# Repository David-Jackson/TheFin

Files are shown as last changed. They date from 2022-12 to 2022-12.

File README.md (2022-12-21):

# The Fin
## v1.03

The Fin is a straight Talon mag fed pump action springer in a small compact frame. Coming in at around 15in (390mm) long! The blaster packs an Espyr spring volume with a side mounted mag to help keep the blaster compact (this is also how I came up with the name for it). Two threaded rods make up the trigger mechanism and the reload action. The rods are hidden behind the center shroud for aesthetics. The blaster utilizes a turn-around much like the Lynx or SLAB to transfer backward airflow into dart throwing power. Picatinny rails or just some iron sights are planned, I just wanted to get one printed to work out any bugs before more design work.

### More details, STLs, BOM, and assembly guide to come.

# The Design

Here is a imgur link to some renders of the blaster: [LINK](https://imgur.com/a/9urtGti)

# Changelog
<details>
<summary>Changes</summary>
  
- 12-21-2022: Additional Changes After Second Build (v1.03)
  1. Updated Parts
     - **Magwell Top**
       - Updated dart guide so the *Pusher* O-ring does not rub against it
     - **Magwell**
       - Updated dart guide so the *Pusher* O-ring does not rub against it
     - **Trigger Catch**
       - Add clearance between *Trigger Catch* and *Front Spacer* (missed in previous release, changes were present in step file though)
- 12-20-2022: Updates After Second Build (v1.02)
  1. Updated Parts 
     - **Grip Core**
       - Implement new trigger spring design
     - **Grip Core Plate**
       -  Implement new trigger spring design
     - **Pusher**
       - New keyway design
     - **Turn Around**
       - Update slot for new keyway design on *Pusher*
     - **Turn Around Spacer**
       - Update slot for new keyway design on *Pusher*
       - Update clearance for *Pump Grip*
     - **Magwell**
       - Update slot for new keyway design on *Pusher*
     - **Magwell Top**
       - Update slot for new keyway design on *Pusher*
     - **Center Block**
       - Update clearance for *Pump Grip*
     - **Pump Grip Core**
       - Add cutaway to give access to screws attaching *Reload Block* to *Plunger Catch Cylinder* (Makes assembly easier)
     - **Reload Block**
       - Add clearance between *Reload Block* and *Front Spacer*
     - **Front Spacer**
       - Add clearance between *Front Spacer*, *Reload Block*, and *Plunger Cylinder Catch*
  2. New Parts
     - **Plunger Catch - Medium**
       - Keyway in the *Plunger Catch* cut in half
       - Use if your tigger is too hard to pull because of the compressed spring force on the *Plunger Catch*
- 12-15-2022: Huge Design and Clearance update.
  1. Updated Parts (v1.01)
     - **Center Block**
       - Formerly *Plunger Lock Block*
       - Updated screw holes, support bar, and barrel clearance
       - Added chamfer for easy plunger tube insertion
       - Added clearance for Pump Grip
     - **Front Spacer**
       - Updated support bar and barrel clearance
       - Updated clearance for trigger catch
     - **Fronter Spacer**
       - Updated support bar and barrel clearance
     - **Grip Core**
       - Decreased internal support structure to save plastic
       - Updated screw hole clearance
     - **Grip Core Plate**
       - Added clearance between Grip Core and Grip Core Plate
       - Added support structure to keep trigger way square
       - Updated screw hole clearance
     - **Grip Left**
       - Updated screw hole clearance
       - Updated Google Drive file link
     - **Grip Right**
       - Updated screw hole clearance
       - Updated Google Drive file link
     - **Mag Release**
       - Added clearance between Mag Release, Magwell, and Magazine
       - Updated screw hole clearance
     - **Magwell**
       - Added clearance for Magazine
       - Adjusted Trigger Bracket clearance
       - Updated screw hole clearance
     - **Magwell Top**
       - Added features to make part easier to print
       - Removed part of bracket that interfered with Turn Around
       - Updated screw support structure between Magwell Top and Turn Around
       - Updated clearance for Magazine lips
       - Updated clearance for screw holes and Pusher
     - **Nose**
       - Updated support bar and barrel clearance
     - **Plunger Catch**
       - Formerly *Plunger Catch Release*
       - Redesigned for new square Plunger Shaft
     - **Plunger Catch Cylinder**
       - Formerly *Plunger Cap Cylinder*
       - Added clearance for new Plunger Shaft
       - Updated screw hole clearance
     - **Pump Grip**
       - Removed some structure to make clearance for screw heads off of the Center Block
       - Updated screw holes and support bar clearance
       - Updated Google Drive file link
     - **Pump Grip Core**
       - Removed some extra structure to save plastic
       - Updated screw holes and support bar clearance
     - **Pusher**
       - Added clearance between Pusher, Magwell, and Magwell Top
       - Updated screw hole clearance
     - **Ram Bracket**
       - Moved screw head cut-out to accommodate new screw support structure on the Magwell Top and Turn Around
       - Updated screw hole clearance
     - **Reload Block**
       - Formerly *Plunger Cap Block*
       - Added clearance for Pump Grip and Spacers
       - Updated screw hole clearance
     - **Short Plunger Cup**
       - Modified part to accommodate new square Plunger Shaft
       - Added internal structure to support new square Plunger Shaft
       - Updated screw hole clearance
     - **Trigger Catch**
       - Updated threaded rod hole size
       - Modified ramp to accommodate new Plunger Catch
     - **Turn Around**
       - Removed O-Rings from plunger tube and barrel well
       - Updated screw support structure between Magwell Top and Turn Around
       - Adjusted Trigger Bracket and Pusher clearance
       - Updated screw holes, support bar, threaded rod, and barrel clearance
     - **Turn Around Spacer**
       - Updated support bar, threaded rod, and barrel clearance
       - Adjusted Pusher clearance
  2. New Parts
     - **Plunger Cap**
       - Removed shaft from Short Plunger
       - Added structure to attach Plunger Shaft
       - Changed 3 1/2 inch machine screw to 2 inch, Still #10-32
       - Adjusted O-ring clearance
     - **Plunger Shaft**
       - New square shaft and key
  3. Removed Parts
     - **Short Plunger**
       - Split into Plunger Cap and Plunger Shaft
       - Old design did not withstand the forces of a compressed K25 spring
- 12-05-2022: Added drill stencil STL files for support bars
- 12-04-2022: Initial Release  (v1.00)
</details>

<!-- BOM -->

<!-- Assembly Video -->

<!-- Q&A -->

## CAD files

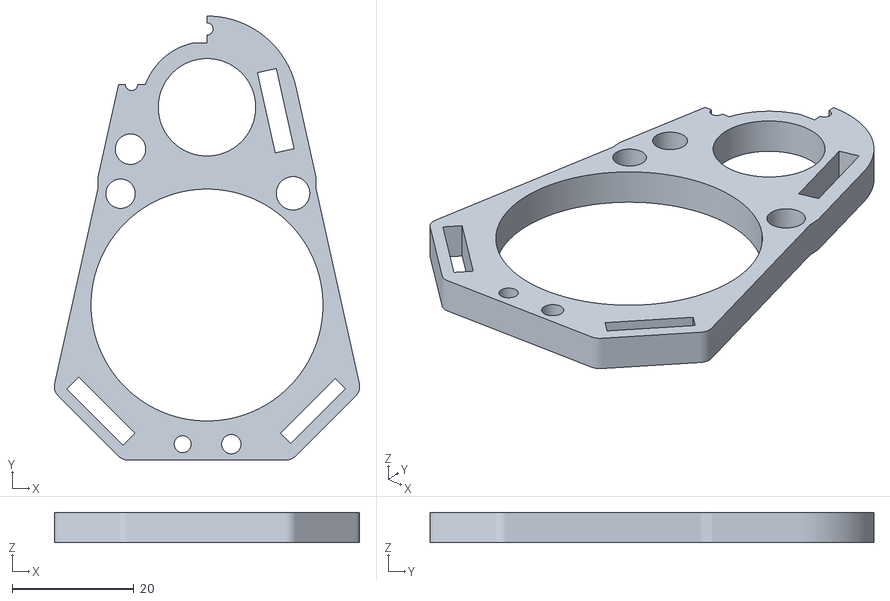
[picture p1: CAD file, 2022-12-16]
Files/STLs/Debugging/Clearance Test.STL
50.2 x 73.0 x 5.00

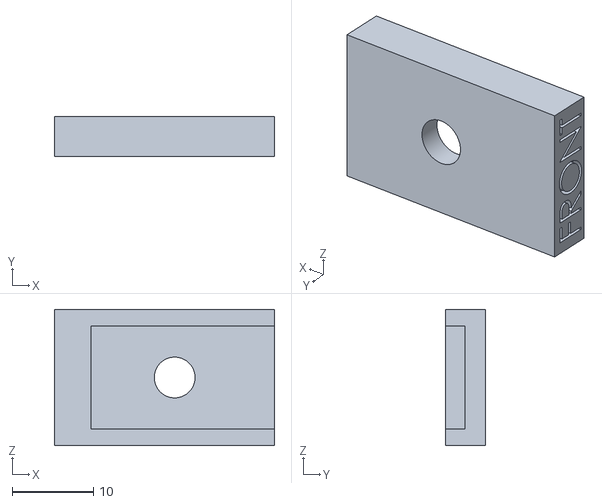
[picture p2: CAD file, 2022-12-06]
Files/STLs/Drill Stencil/Front Stencil.STL
27.0 x 4.88 x 16.7

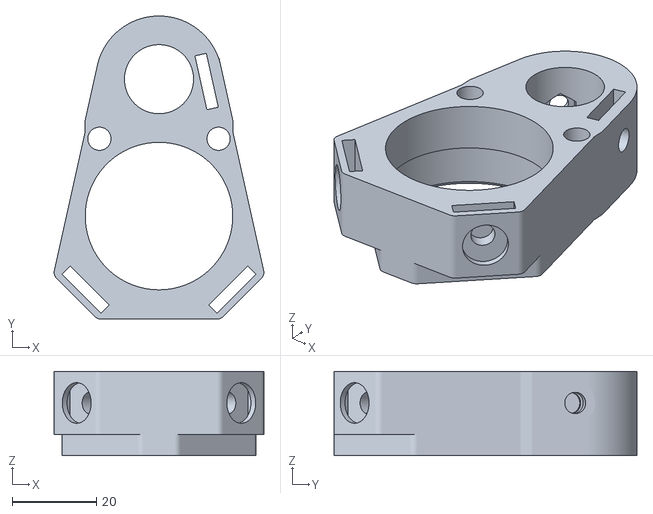
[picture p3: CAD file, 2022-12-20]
Files/STLs/Primary Color/Center Block.STL
49.8 x 71.9 x 20.0

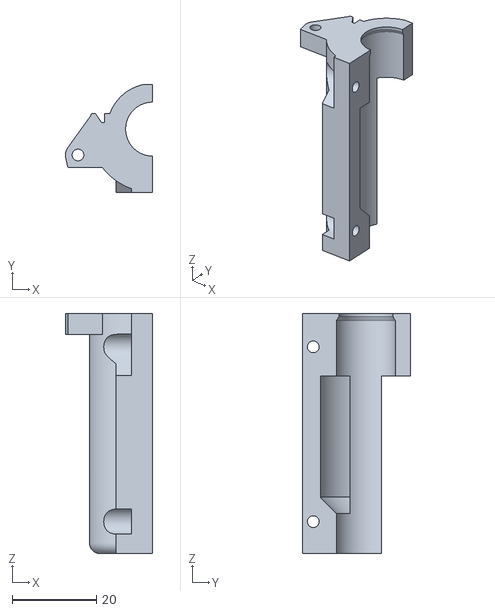
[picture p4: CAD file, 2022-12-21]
Files/STLs/Secondary Color/Magwell Top.STL
20.7 x 25.5 x 57.0

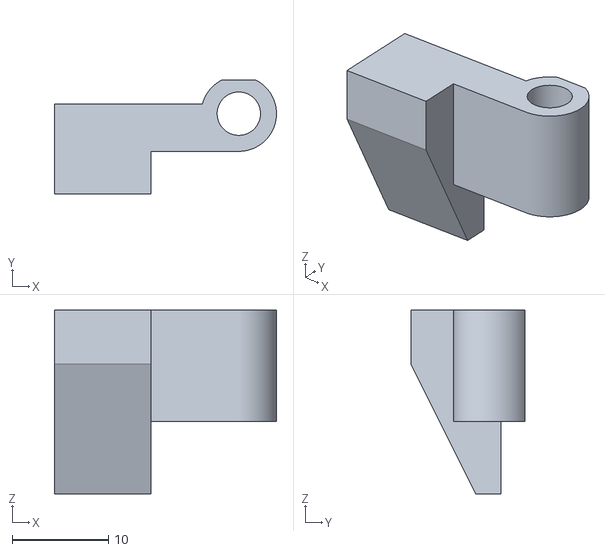
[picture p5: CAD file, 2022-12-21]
Files/STLs/Tertiary Color/Trigger Catch.STL
23.1 x 11.9 x 19.1

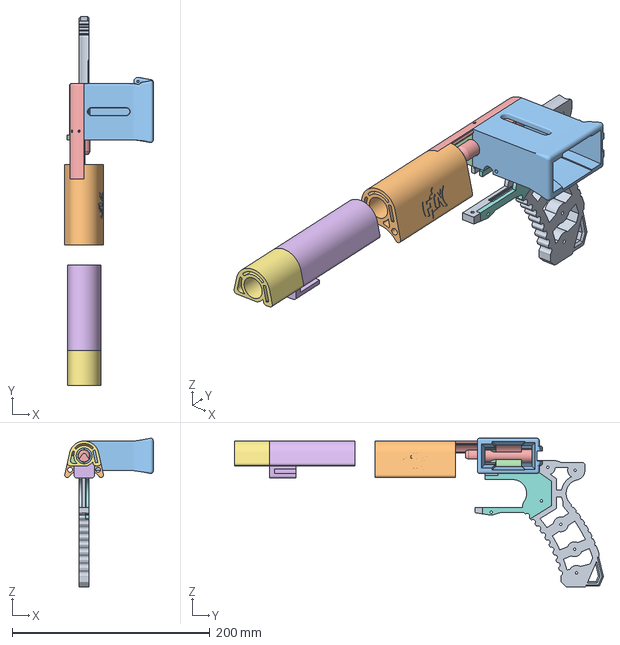
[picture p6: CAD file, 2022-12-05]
Files/TheFin - Secondary Color Parts.3mf
89.6 x 373.4 x 150.4 mm

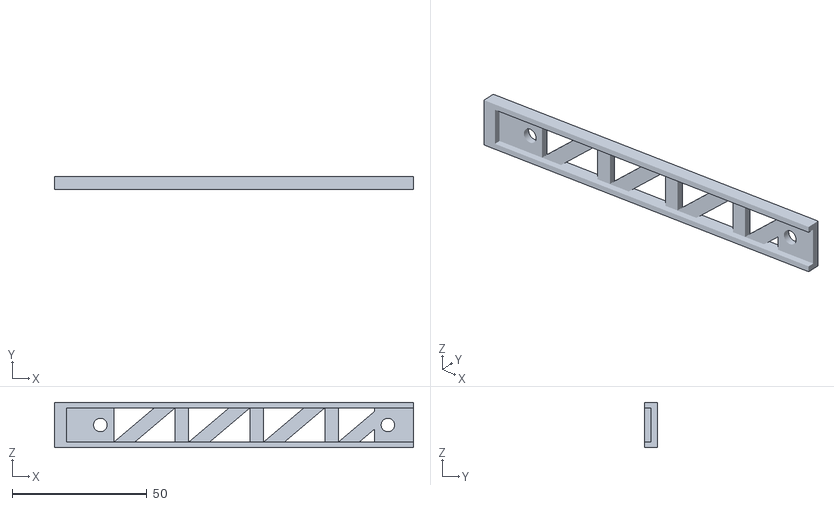
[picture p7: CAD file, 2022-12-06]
Files/STLs/Drill Stencil/Back Stencil.STL
133.1 x 4.88 x 16.7

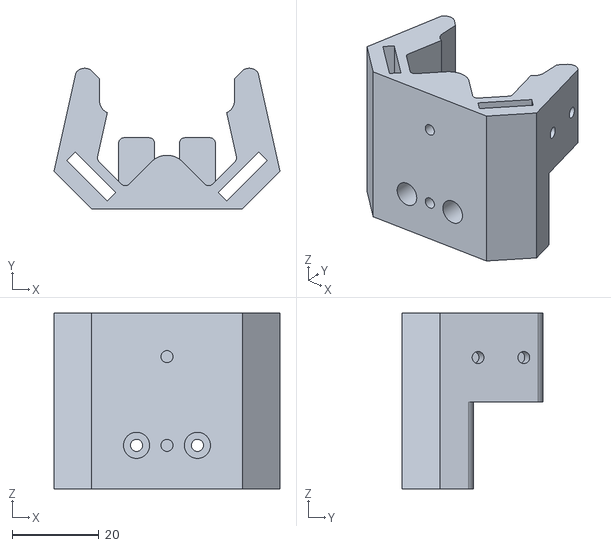
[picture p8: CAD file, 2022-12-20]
Files/STLs/Primary Color/Pump Grip Core.STL
52.0 x 32.3 x 40.4

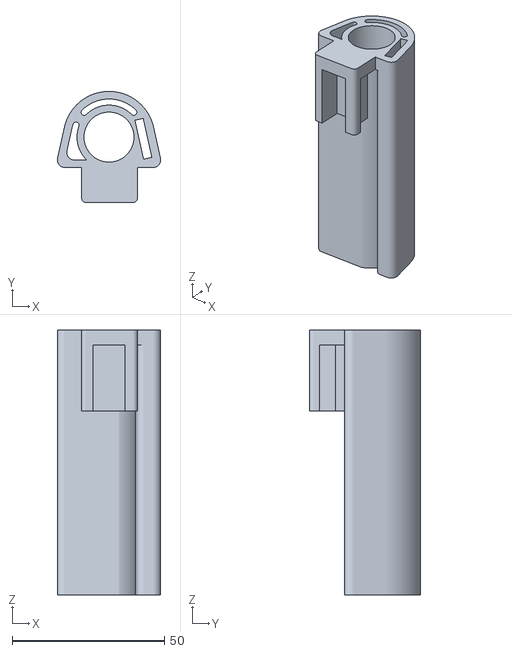
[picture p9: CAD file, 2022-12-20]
Files/STLs/Secondary Color/Front Spacer.STL
33.9 x 36.5 x 87.0

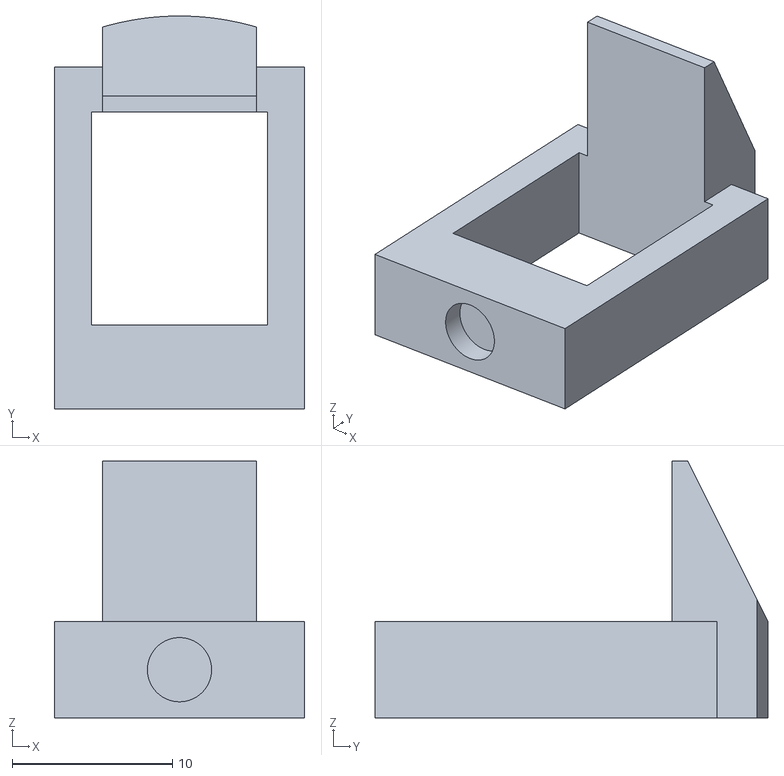
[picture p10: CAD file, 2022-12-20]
Files/STLs/Tertiary Color/Plunger Catch - Medium.STL
15.6 x 24.5 x 16.0

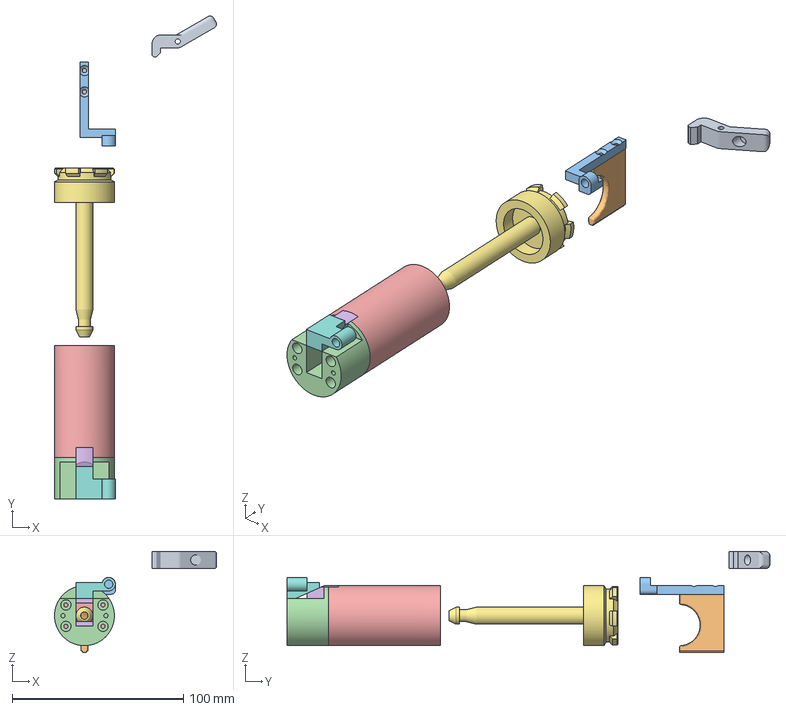
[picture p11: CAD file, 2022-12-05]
Files/TheFin - Tertiary Color Parts.3mf
94.6 x 282.0 x 59.0 mm

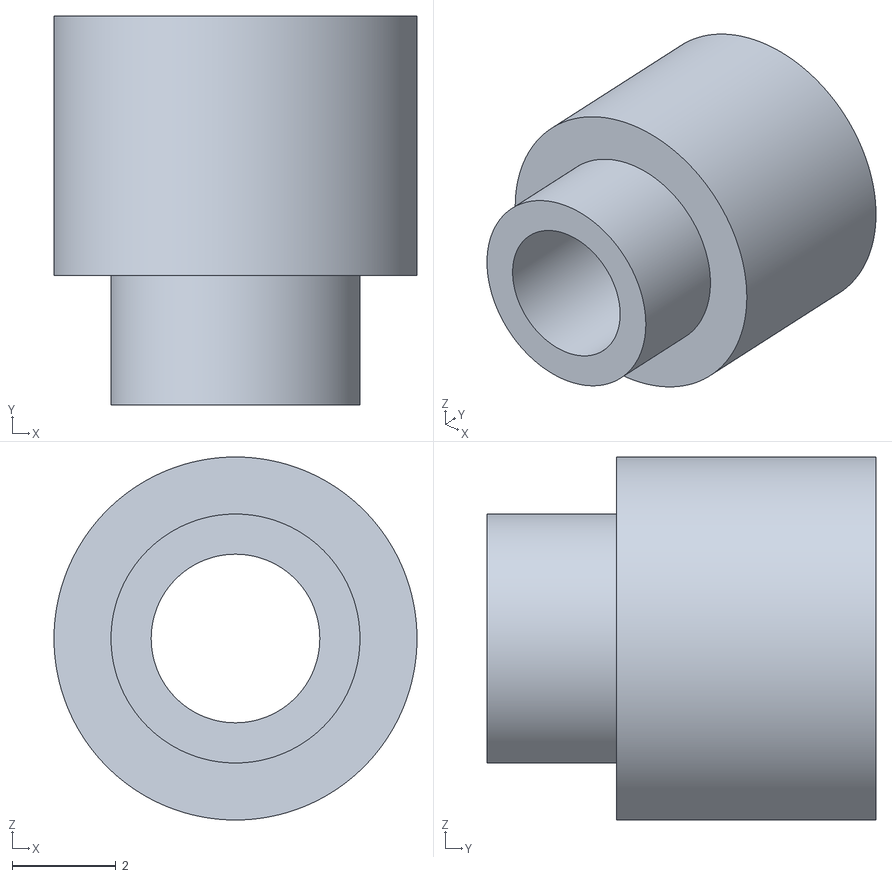
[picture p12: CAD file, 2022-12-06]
Files/STLs/Drill Stencil/Hole guide.STL
7.00 x 7.50 x 7.00

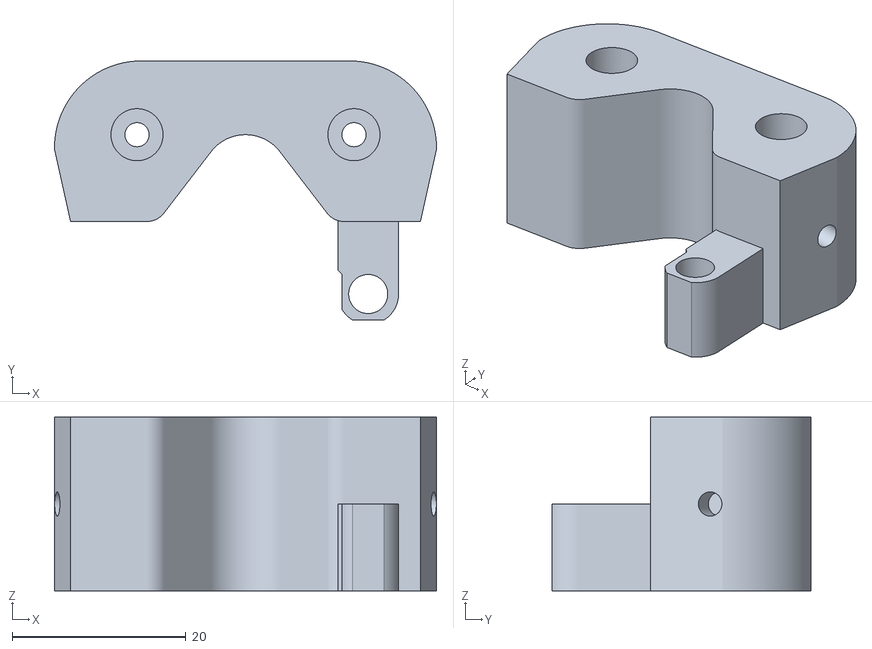
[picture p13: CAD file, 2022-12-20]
Files/STLs/Primary Color/Reload Block.STL
44.0 x 29.9 x 20.0

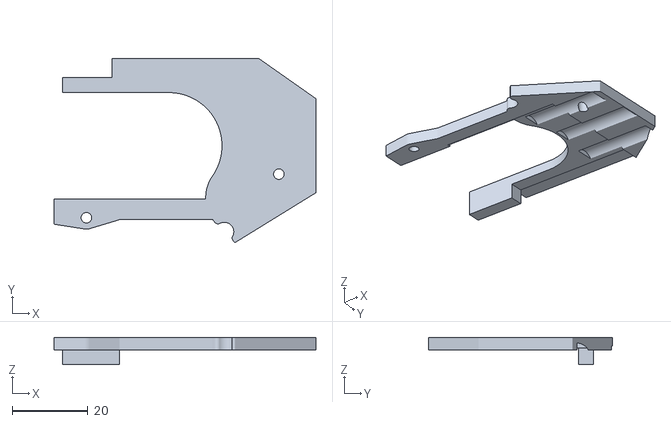
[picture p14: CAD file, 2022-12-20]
Files/STLs/Secondary Color/Grip Core Plate.STL
69.1 x 48.6 x 7.20

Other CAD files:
Files/STLs/Tertiary Color/Short Plunger Cup.STL
Files/STLs/Primary Color/Ram Brace.STL
Files/STLs/Secondary Color/Turn Around Spacer.STL
Files/STLs/Tertiary Color/Plunger Catch Spacer.STL
Files/STLs/Secondary Color/Fronter Spacer.STL
Files/STLs/Tertiary Color/Plunger Cap.STL
Files/STLs/Tertiary Color/Plunger Catch Cylinder.STL
Files/STLs/Tertiary Color/Plunger Catch.STL
